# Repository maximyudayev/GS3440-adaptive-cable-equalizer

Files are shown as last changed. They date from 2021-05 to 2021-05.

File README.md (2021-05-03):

# SDI Adaptive Cable Equalizer - Semtech GS3440
This equalizer board was built as part of my Hardware Design course at KU Leuven - Campus GroupT in academic year 2020-2021, taught by the awesome Gorik :wink:

PCB front side:
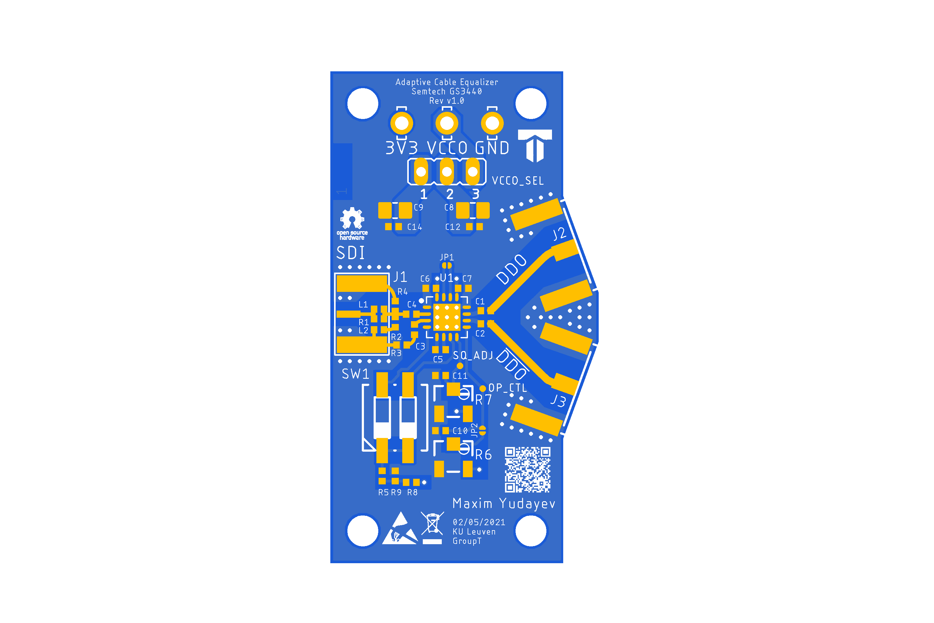
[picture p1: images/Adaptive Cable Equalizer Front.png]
PCB front side


PCB back side:
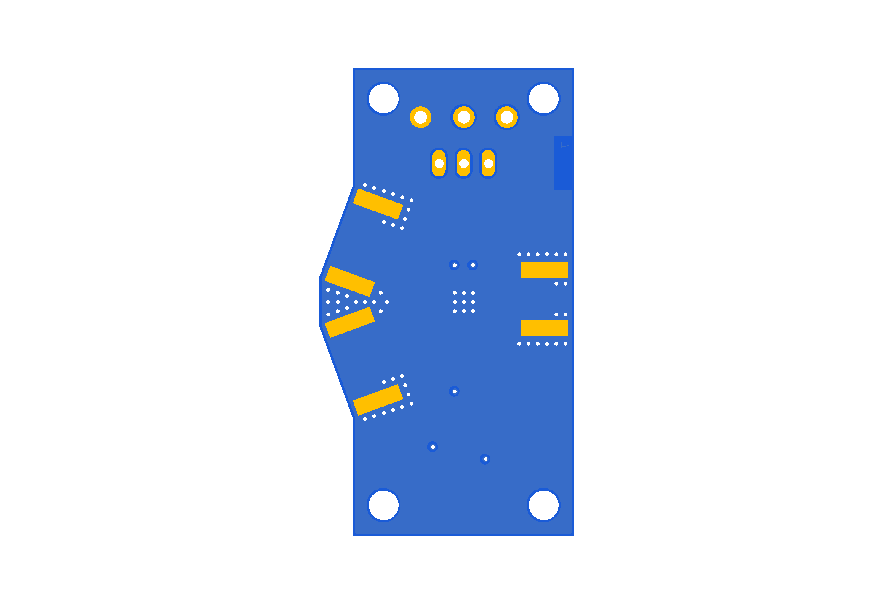
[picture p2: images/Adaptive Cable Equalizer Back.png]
PCB back side


Mechanical layer details:
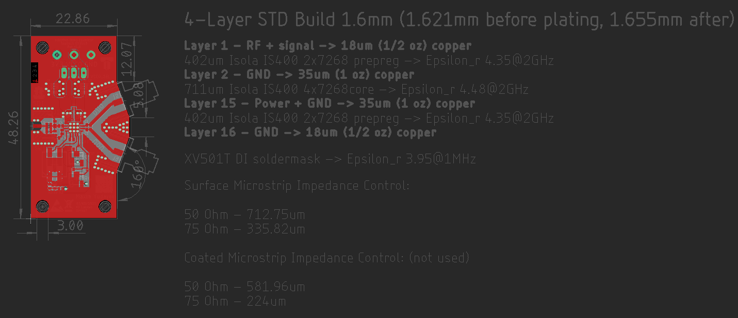
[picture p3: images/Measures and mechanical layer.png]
Mechanical layer details


50 Ohm trace width:
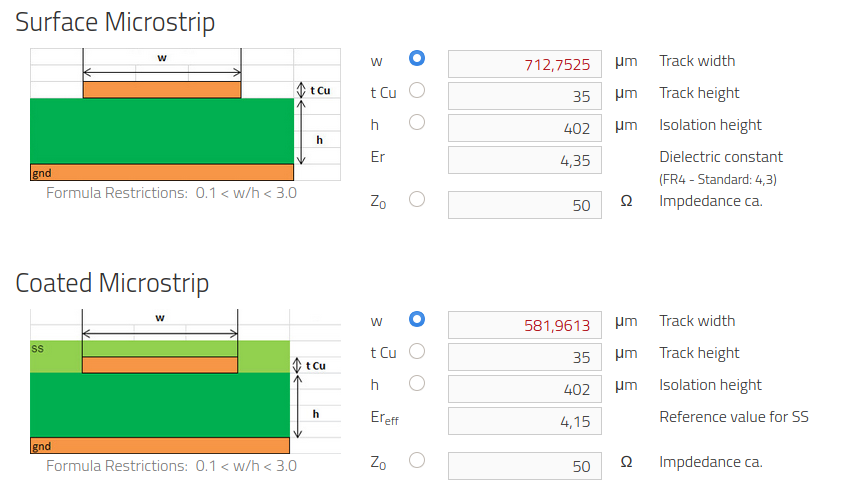
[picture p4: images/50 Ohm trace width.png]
50 Ohm trace width


75 Ohm trace width:
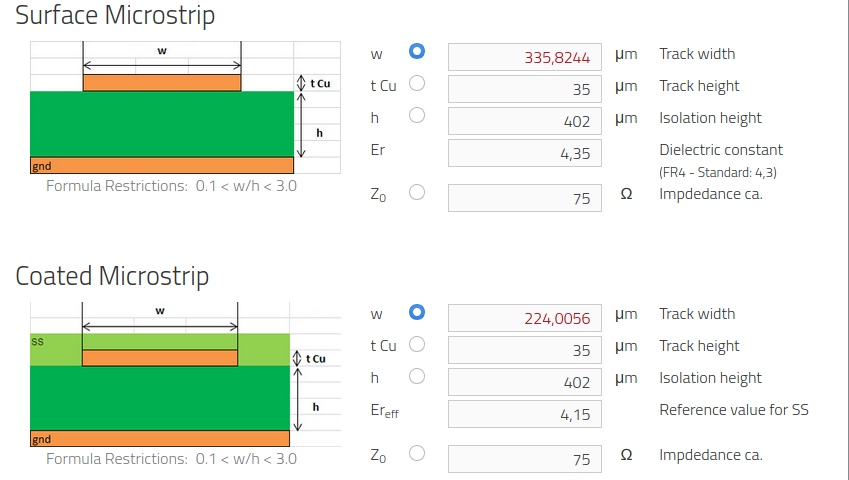
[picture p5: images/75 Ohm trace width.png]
75 Ohm trace width


All the design files are under GPL3 and can be freely used for personal projects where this device can be of use.

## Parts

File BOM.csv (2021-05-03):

Qty | Value | Device | Package | Parts | Description
1 |  | JP2E | JP2 | VCCO_SEL | JUMPER
1 |  | R0402 | 0402 | R4
2 | 100n | C0402 | 0402 | C12, C14
4 | 10n | C0402 | 0402 | C6, C7, C10, C11
2 | 10u | C-EUC0805K | C0805K | C8, C9 | CAPACITOR, European symbol
1 | 1k21 | R0402 | 0402 | R9
2 | 1u | C0402 | 0402 | C3, C4
1 | 219-02J | 219-02J | CTS-219-02J | SW1 | Surface Mount DIP Switch Series 219 SMT
1 | 221 | R0402 | 0402 | R5
1 | 365 | R0402 | 0402 | R8
1 | 37R4 | R0402 | 0402 | R3
1 | 470n | C0402 | 0402 | C5
2 | 4n7 | L0402 | 0402 | L1, L2
2 | 4u7 | C0402 | 0402 | C1, C2
2 | 5k | TRIM_EU-3223W | 3223W | R6, R7 | POTENTIOMETER
2 | 75 | R0402 | 0402 | R1, R2
1 | GS3440 | GS3440 | QFN65P400X400X90-17T260N | U1 | Adaptive Cable Equalizer
1 | HD-BNC | HD-BNC | 034_1018_12G | J1 | HD BNC 75 Ohm
2 | SMA132357 | SMA132357 | SMA | J2, J3 | SMA 50 Ohm End Launch Jack Receptacle - Round Contact
2 | SMD-JUMPER | SMD-JUMPER | SMD-JUMPER | JP1, JP2
3 | TAB_37800568(MSTIN) | TAB_37800568(MSTIN) | HOLE_1-3 | 3V3, GND, VCCO
2 | TPTP06R | TPTP06R | TP06R | OP_CTL, SQ_ADJ | Test pad

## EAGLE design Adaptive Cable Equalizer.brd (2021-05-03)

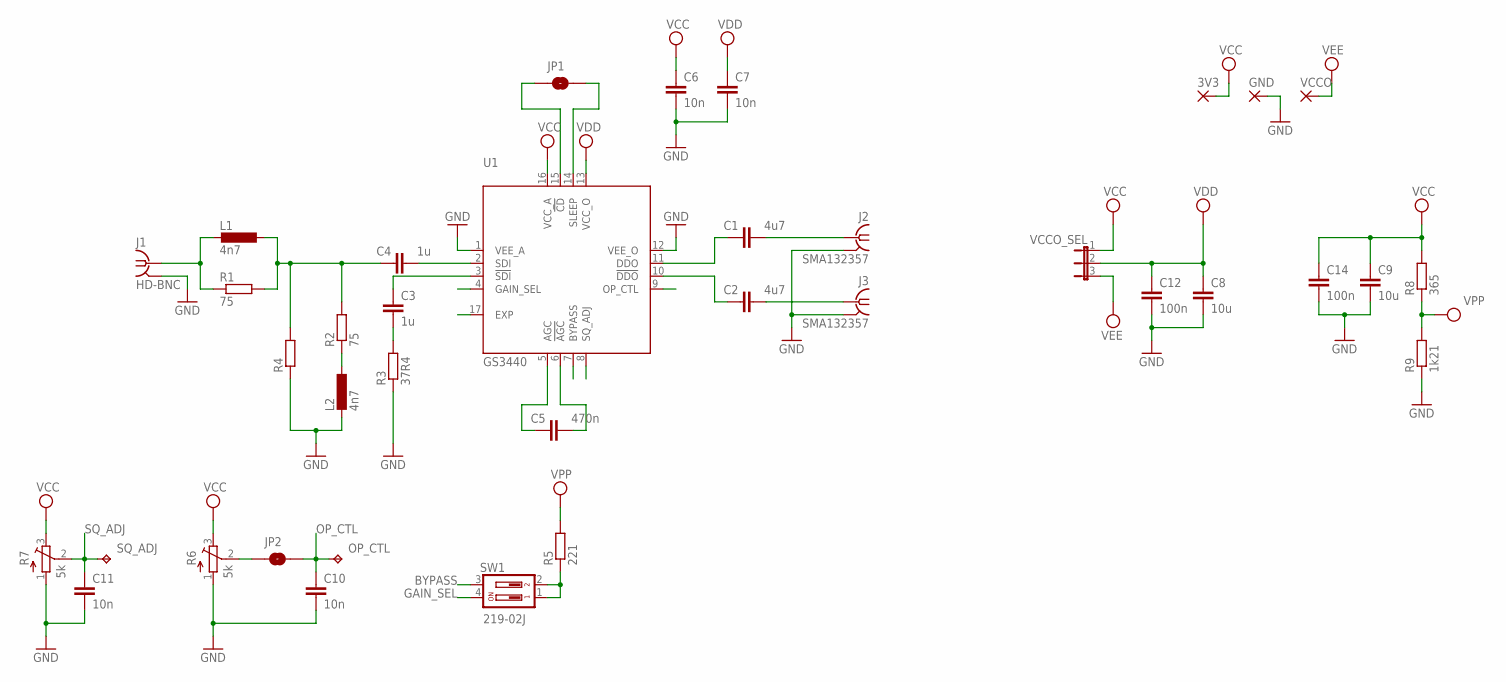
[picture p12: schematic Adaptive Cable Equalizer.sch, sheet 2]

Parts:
3V3: TAB_37800568(MSTIN); HOLE_1-3
C1, C2: 4u7; 0402
C3, C4: 1u; 0402
C5: 470n; 0402
C6, C7, C10, C11: 10n; 0402
C8, C9: 10u; C0805K
C12, C14: 100n; 0402
GND: TAB_37800568(MSTIN); HOLE_1-3
J1: HD-BNC; 034_1018_12G
J2, J3: SMA132357; SMA
JP1, JP2: SMD-JUMPER
L1, L2: 4n7; 0402
OP_CTL: TPTP06R; TP06R
R1, R2: 75; 0402
R3: 37R4; 0402
R4: R0402; 0402
R5: 221; 0402
R6, R7: 5k; 3223W
R8: 365; 0402
R9: 1k21; 0402
SQ_ADJ: TPTP06R; TP06R
SW1: 219-02J; CTS-219-02J
U1: GS3440; QFN65P400X400X90-17T260N
VCCO: TAB_37800568(MSTIN); HOLE_1-3
VCCO_SEL: JP2E; JP2

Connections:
!CD: JP1.P$1 (1), U1.15 (!CD)
BYPASS: SW1.3, U1.7 (BYPASS)
GAIN_SEL: SW1.4, U1.4 (GAIN_SEL)
GND: C6.2, C7.2, C8.2, C9.2, C10.2, C11.2, C12.2, C14.2, GND.P$1, J1.G@1 (2), J1.G@2 (2), J1.G@3 (2), J1.G@4 (2), J2.G@1 (2), J2.G@2 (2), J2.G@3 (2), J2.G@4 (2), J3.G@1 (2), J3.G@2 (2), J3.G@3 (2), J3.G@4 (2), L2.2, R3.1, R4.1, R6.1 (A), R7.1 (A), R9.1, U1.1 (VEE_A), U1.12 (VEE_O), U1.17 (EXP)
unnamed: C2.2, J3.1
unnamed: C1.2, J2.1
unnamed: C2.1, U1.10 (!DDO)
unnamed: C1.1, U1.11 (DDO)
unnamed: J1.P$1 (1), L1.2, R1.1
unnamed: C4.1, L1.1, R1.2, R2.2, R4.2
unnamed: C3.1, U1.3 (!SDI)
unnamed: C4.2, U1.2 (SDI)
unnamed: L2.1, R2.1
unnamed: C5.1, U1.5 (AGC)
unnamed: C3.2, R3.2
unnamed: C5.2, U1.6 (!AGC)
unnamed: JP2.P$1 (1), R6.2 (S)
unnamed: JP1.P$2 (2), U1.14 (SLEEP)
unnamed: R5.1, SW1.1, SW1.2
OP_CTL: C10.1, JP2.P$2 (2), OP_CTL.TP, U1.9 (OP_CTL)
SQ_ADJ: C11.1, R7.2 (S), SQ_ADJ.TP, U1.8 (SQ_ADJ)
VCC: 3V3.P$1, C6.1, C9.1, C14.1, R6.3 (E), R7.3 (E), R8.2, U1.16 (VCC_A), VCCO_SEL.1
VDD: C7.1, C8.1, C12.1, U1.13 (VCC_O), VCCO_SEL.2
VEE: VCCO.P$1, VCCO_SEL.3
VPP: R5.2, R8.1, R9.2

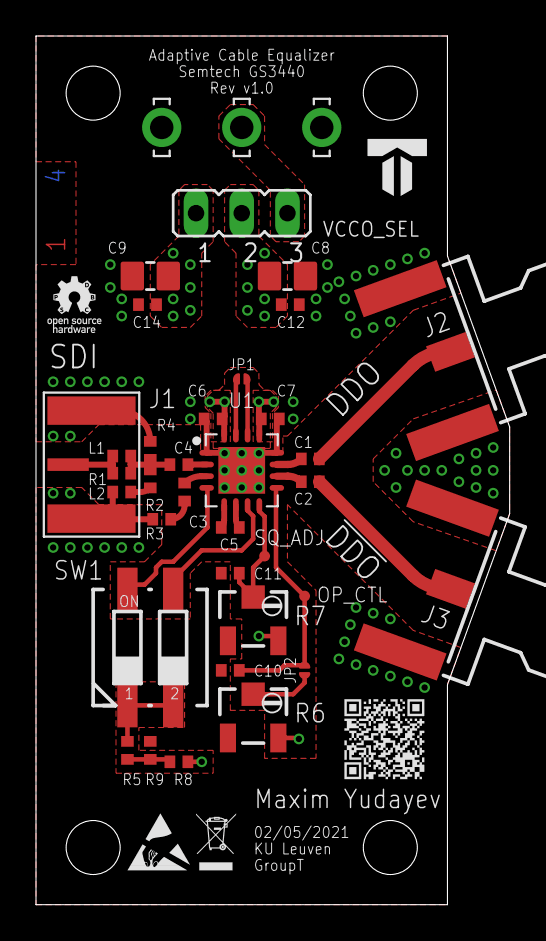
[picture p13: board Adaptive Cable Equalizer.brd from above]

Board: 4 copper layers, 26.3 x 48.3 mm, 37 parts (0 on the bottom side), 25 nets.

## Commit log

2021-05-03 Full design upload. No stitching vias
    +: Schematic
    +: Board layout
    +: BOM
    +: Silkscreen artwork and QR-code
    +: Mechanical layer details, buildup and stackup
    +: Images
    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
    [Adaptive Cable Equalizer.brd, Adaptive Cable Equalizer.sch, BOM.csv]
2021-05-03 Updated PCB images with better resolution
2021-05-03 Improved decoupling capacitor placement
    +: Added polygons for IC's VCC_A and VCC_O supplies
    +: Added multiple vias around distant "bulk" capacitors
    [Adaptive Cable Equalizer.brd]
